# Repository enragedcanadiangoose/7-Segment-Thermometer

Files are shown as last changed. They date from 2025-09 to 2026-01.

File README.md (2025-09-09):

# 7-Segment-Thermometer
A simple project using two thermal sensors (DS18B20) an arduino nano and a four digit common cathode seven-segment display

<!-- TABLE OF CONTENTS -->
<details>
  <summary>Table of Contents</summary>
  <ol>
    <li>
      <a href="#about-the-project">About The Project</a>
    </li>
    <li>
      <a href="#getting-started">Getting Started</a>
      <ul>
        <li><a href="#Prerequisites">Prerequisites</a></li>
        <li><a href="#Installation">Installation</a></li>
        <li><a href="#building-the-circuit">Building the circuit</a></li>
        <li><a href="#how-it-works">How It Works</a></li>
      </ul>
    </li>
    <li><a href="#roadmap">Roadmap</a></li>
    <li><a href="#contact">Contact</a></li>
        <li><a href="#license">License</a></li>
  </ol>
</details>

## About The Project
This is a simple project created using an Arduino Nano paired with two thermal sensors (DS18B20 or compatible) and a seven-segment display used to show the temperature both inside and outside of my room. 
<p align="right">(<a href="#readme-top">back to top</a>)</p>

<!-- GETTING STARTED -->
## Getting Started

Replicating the project

### Prerequisites

* Arduino IDE
    * install from the Arduino library manager
        * OneWire.h
        * DallasTemperature.h

### Installation

1. Clone the repo
```sh
git clone https://github.com/enragedcanadiangoose/7-Segment-Thermometer.git
```
2. Open the "./7-Segment-Thermometer/Thermometer/" folder in the Arduino IDE

### Building The Circuit

Schematic  
<p>You can follow this diagram to replicate the circuit I used, this should let the code function with no modification</p>
Schematic  
<p>Here is the version that I built on a prototyping breadboard, it's a bit of a sloppy prototype but it works</p>

### How It Works

* The Arduino polls the active thermal sensor every 30s for up to keep the data being displayed up to date
    * The display will blank during this time since the Arduino can't draw the display and poll the sensors simultaneously
* The desired thermal sensor is selected using the toggle switch
* The presence of the decimal point indicates if the temperature is positive or negative
    * on = ≥ 0
    * off = ≤ 0
<p align="right">(<a href="#readme-top">back to top</a>)</p>

## Roadmap

<p>At some point a run of PCBs may be manufactured</p>
<p align="right">(<a href="#readme-top">back to top</a>)</p>

## Contact
<p>email: astew2693@gmail.com</p>
<p align="right">(<a href="#readme-top">back to top</a>)</p>

## License

<p>see <a href="https://github.com/enragedcanadiangoose/7-Segment-Thermometer/blob/main/LICENSE">LICENSE</a> for details</p>

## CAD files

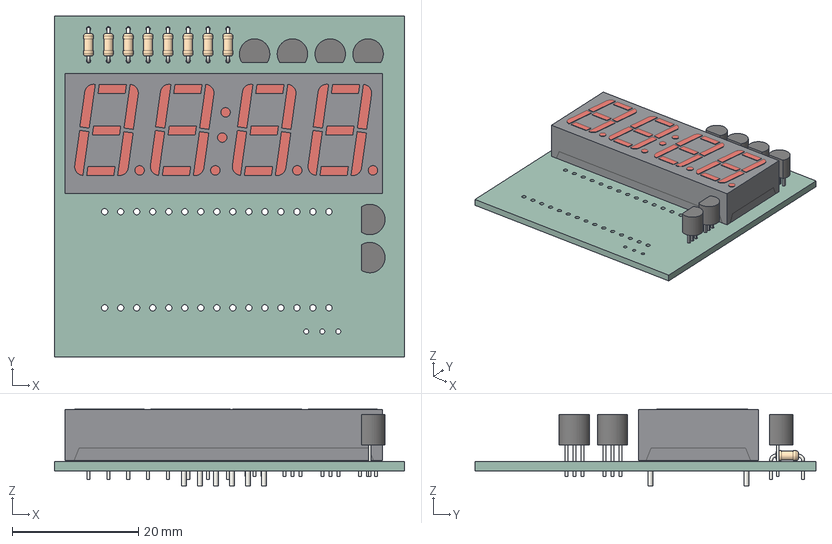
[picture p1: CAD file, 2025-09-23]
schematic/Thermometer.step
55.5 x 54.0 x 12.2 mm
R_Axial_DIN0204_L3.6mm_D1.6mm_P5.08mm_Horizontal x 8
CA56-12EWA
TO-92_Inline x 6
Thermometer_PCB

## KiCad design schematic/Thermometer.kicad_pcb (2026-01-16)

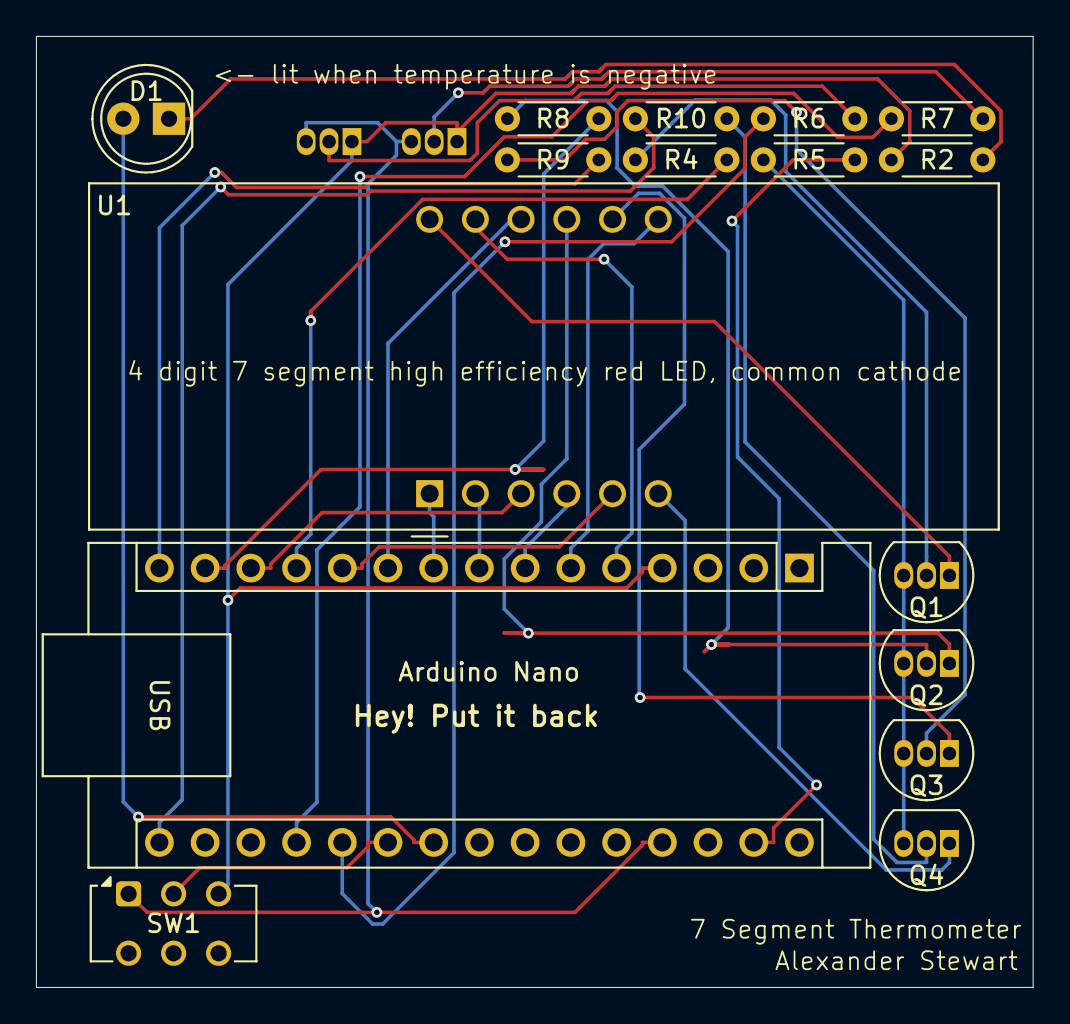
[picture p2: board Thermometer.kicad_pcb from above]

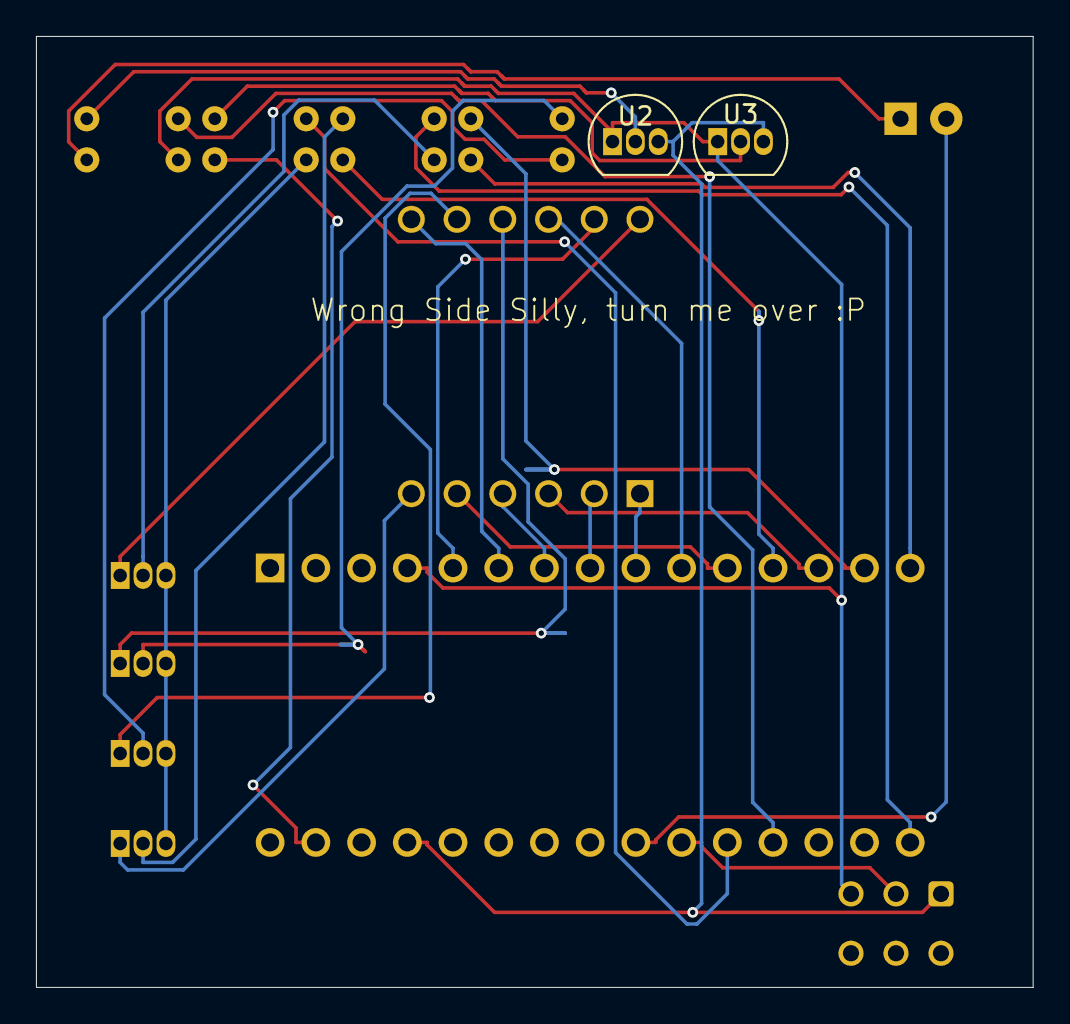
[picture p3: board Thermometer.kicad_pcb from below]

Board: 2 copper layers, 55.4 x 52.8 mm, 18 parts (2 on the bottom side), 31 nets.

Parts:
Arduino Nano: Arduino_Nano_v2.x; Arduino_Nano
D1: LED; LED_D5.0mm
Q1, Q2, Q3, Q4: BC547; TO-92_Inline
R2: 220; R_Axial_DIN0204_L3.6mm_D1.6mm_P5.08mm_Horizontal
R4, R8, R9, R10: 100k; R_Axial_DIN0204_L3.6mm_D1.6mm_P5.08mm_Horizontal
R5: 550; R_Axial_DIN0204_L3.6mm_D1.6mm_P5.08mm_Horizontal
R6, R7: 4.7k; R_Axial_DIN0204_L3.6mm_D1.6mm_P5.08mm_Horizontal
SW1: SW_SPDT; SW_CK_JS202011CQN_DPDT_Straight
U1: CC56-12EWA; CA56-12EWA
U2, U3: DS18B20; TO-92_Inline

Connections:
unnamed: Arduino Nano.27 (+5V), SW1.1 (A), U2.3 (V_{DD}), U3.3 (V_{DD})
unnamed: Arduino Nano.19 (A0), R7.2
unnamed: Arduino Nano.20 (A1), R6.2
unnamed: Arduino Nano.21 (A2), SW1.2 (B)
unnamed: Arduino Nano.22 (A3), D1.2 (A)
unnamed: Arduino Nano.5 (D2), U1.11 (a)
unnamed: Arduino Nano.6 (D3), U1.7 (b)
unnamed: Arduino Nano.7 (D4), U1.4 (c)
unnamed: Arduino Nano.8 (D5), U1.2 (d)
unnamed: Arduino Nano.9 (D6), U1.1 (e)
unnamed: Arduino Nano.10 (D7), U1.10 (f)
unnamed: Arduino Nano.11 (D8), U1.5 (g)
unnamed: Arduino Nano.12 (D9), R4.1
unnamed: Arduino Nano.13 (D10), U1.3 (DPX)
unnamed: Arduino Nano.14 (D11), R8.1
unnamed: Arduino Nano.15 (D12), R9.1
unnamed: Arduino Nano.16 (D13), R10.1
unnamed: Arduino Nano.29 (GND), R5.1
unnamed: D1.1 (K), R2.1
unnamed: Q1.2 (B), R4.2
unnamed: Q1.1 (C), U1.12 (CC1)
unnamed: Q1.3 (E), Q2.3 (E), Q3.3 (E), Q4.3 (E), R5.2
unnamed: Q2.2 (B), R8.2
unnamed: Q2.1 (C), U1.9 (CC2)
unnamed: Q3.2 (B), R9.2
unnamed: Q3.1 (C), U1.8 (CC3)
unnamed: Q4.2 (B), R10.2
unnamed: Q4.1 (C), U1.6 (CC4)
unnamed: Arduino Nano.4 (GND), R2.2, SW1.3 (C), U2.1 (GND), U3.1 (GND)
unnamed: R7.1, U2.2 (DQ)
unnamed: R6.1, U3.2 (DQ)

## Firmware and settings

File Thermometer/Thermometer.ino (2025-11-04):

#include "SevenSegment.cpp"
#include <OneWire.h>
#include <DallasTemperature.h>

long long time; //stores the previous millis value for refreshing the data
bool lastState; //used to store the previous state of A2 since there are no interrupts on analogue pins

SevenSegment display(2, 3, 4, 5, 6, 7, 8, 10, 9, 11, 12, 13); //initialize the display using the pins specified for each display segment

OneWire sensor1(A0); //instantiate the 2 onewire temperature sensors
OneWire sensor2(A1);

DallasTemperature indoor(&sensor1); //instantiate the DallasTemperature object used to get the temperature in degrees celcius from the probes
DallasTemperature outdoor(&sensor2);

void setup() {
  pinMode(A2, INPUT); //A2 is the switch between the two couples
  pinMode(A3, INPUT);
  display.begin(); //initializes the display class
  indoor.begin();
  outdoor.begin();

  time = millis(); //sets the timer to be the current runtime
  lastState = digitalRead(A2); //sets the lastState to be the current state of A2, for detection of changes to A2
  Serial.begin(9600);
  if(digitalRead(A2)){ //if A2 is high gets the temperature of the indoor sensor
      indoor.requestTemperatures();
      display.setNumber(abs(indoor.getTempCByIndex(0)*100), (abs(indoor.getTempCByIndex(0)) >= 0)); //sets the display to the temperature of the indoor sensor
  }
  else{ //otherwise gets the temperature of the outdoor sensor
      outdoor.requestTemperatures();
      display.setNumber(abs(outdoor.getTempCByIndex(0)*100), (outdoor.getTempCByIndex(0) >= 0)); //sets the display to the outdoor temperature
  }
}

void loop() {
  if(digitalRead(A2) != lastState){ //if the A2 switch is switched
    time -= (30000); //subtracts 30000 from the time forcing the sensor to refresh
    lastState = digitalRead(A2); //sets the last state to be the current state
  }
  else if(time+30000<millis()){ //runs after 30s or if time is 30 000ms less than the millis() timer
    time = millis(); //sets the time to be the current timer
    if(digitalRead(A2)){ //if A2 is high gets the temperature of the indoor sensor
      indoor.requestTemperatures();
      display.setNumber(abs(indoor.getTempCByIndex(0)*100), (abs(indoor.getTempCByIndex(0)) >= 0));//sets the display to the temperature of the indoor sensor
    }
    else{//otherwise gets the temperature of the outdoor sensor
      outdoor.requestTemperatures();
      display.setNumber(abs(outdoor.getTempCByIndex(0)*100), (outdoor.getTempCByIndex(0) >= 0));//sets the display to the outdoor temperature
    }
  }
  display.drawDisplay(); //draws the 7 segment display
}

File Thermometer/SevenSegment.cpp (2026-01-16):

#include <Arduino.h>

class SevenSegment{
  private:
    int segmentPin[8]; //stores which pin is associated with which segment
    int digitPin[4]; //stores which pin is associated with which digit
    int digitValue[4] = {0}; //stores what value is stored in a given digit
    bool decimal[4] = {0}; //stores wether or not a digit has a decimal on it
    bool state[4] = {0}; //stores if a digit is turned on or not
    const bool CHARACTER_MATRIX[10][7] = { //character matrix containing the 10 possible digits (0-9) each number corrosponding to segments a-g
      {1,1,1,1,1,1,0},
      {0,1,1,0,0,0,0},
      {1,1,0,1,1,0,1},
      {1,1,1,1,0,0,1},
      {0,1,1,0,0,1,1},
      {1,0,1,1,0,1,1},
      {1,0,1,1,1,1,1},
      {1,1,1,0,0,0,0},
      {1,1,1,1,1,1,1},
      {1,1,1,0,0,1,1}
      };

  public:
    SevenSegment(int a, int b, int c, int d, int e, int f, int g, int decimal, int d1, int d2, int d3, int d4){ //constructor for the display, inputs each segment's pin number into an array, or each digits pin number
      segmentPin = {a, b, c, d, e, f, g, decimal};
      digitPin = {d1, d2, d3, d4};
    }
    begin(){ //initializes the display by setting all of it's segment pins and digit pins as outputs
      for(int i = 0; i< 8; i++){
        pinMode(segmentPin[i], OUTPUT);
      }
      for(int i = 0; i< 4; i++){
        pinMode(digitPin[i], OUTPUT);
      }
    }

    allSegments(bool state){ //turns on all the segments of the display at once
      for(int i = 0; i<8; i++)
        digitalWrite(segmentPin[i], state);
      for(int i = 0; i<4; i++)
        digitalWrite(digitPin[i], state);
    }

    setDigit(int digit, int number, bool decimal, bool state){ //sets and individual digit to be a value
      digitValue[digit] = number; //sets the digit value
      this->decimal[digit] = decimal; //sets wether or not the digit has a decimal
      this->state[digit] = state; //sets the digit on or off
    }

    drawDisplay(){ //the draw display method draws the display one digit at a time and relys on object persistance of the human eye to make it appear as though all digits are illuminated simultaneously
      for(int i = 0; i < 4; i++){ //cycles through the 4 digits
        if(state[i]){ //if the current digit is enabled
          digitalWrite(digitPin[i], 1); //turns on the current digit
          for(int j = 0; j<7; j++) //cycles through each segment illuminating it if it is needed
            digitalWrite(segmentPin[j], CHARACTER_MATRIX[digitValue[i]][j]);
          digitalWrite(segmentPin[7], decimal[i]); //enables the decimal if it is needed
          delay(1); //a 1ms delay to allow for the digits to properly illuminate
          allSegments(0); //turns off all the digits to allow for the display of the next digit
          digitalWrite(digitPin[i], 0); //disables the current digit to allow the next one to be displayed
        }
        else{digitalWrite(i, 0);} //disables the current digit if it is not enabled
      }
    }

    setNumber(int number, bool decimal){ //sets a 4 digit number to be displayed on the 7 segment display (if it is a decimal number it is assumed the the decimal is in the middle ex. xx.yy)
      setDigit(3, number%10, 0, 1); //using basic intager math to isolate each digit and setting it on the display
      setDigit(2, (number/10)%10, 0, 1);
      setDigit(1, (number/100)%10, decimal, 1);
      setDigit(0, (number/1000)%10, 0, 1);
    }
};

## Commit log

2025-03-30 Schematic Diagram added
    added a schematic diagram of the circuit
    [Thermometer.kicad_pcb, Thermometer.kicad_sch]
2025-09-09 Updated Readme Formatting and Schematic Comments
    [Thermometer.kicad_sch]
2025-09-11 Optimized the display drawing routines and added optional serial temperature outputs
    [Thermometer.kicad_sch]
2025-09-16 Updated the Character matrix to fix some broken characters
    [SevenSegment.cpp]
2025-09-16 Updated Schematic
    [Thermometer.kicad_sch]
2025-09-23 Created a PCB design for the board
    [Thermometer-B_Cu.gbr, Thermometer-B_Mask.gbr, Thermometer-B_Paste.gbr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]
2025-11-04 Updated Schematic and PCB with (hopefully) final designs
    [Thermometer.dsn, Thermometer.kicad_pcb, Thermometer.kicad_sch]
2026-01-16 Updated error in PCB design
    [Thermometer.dsn, Thermometer.kicad_pcb]
2026-04-23 added printing of temps to the serial port
